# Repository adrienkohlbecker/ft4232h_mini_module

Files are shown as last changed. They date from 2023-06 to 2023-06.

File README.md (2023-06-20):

# FT4232H Mini Module Breakout

A breakout board for FTDI's FT4232H Mini Module. The size is friendly for breadboard use, with two rows of holes left available on each side of the breadboard for wires to come in.

## Board

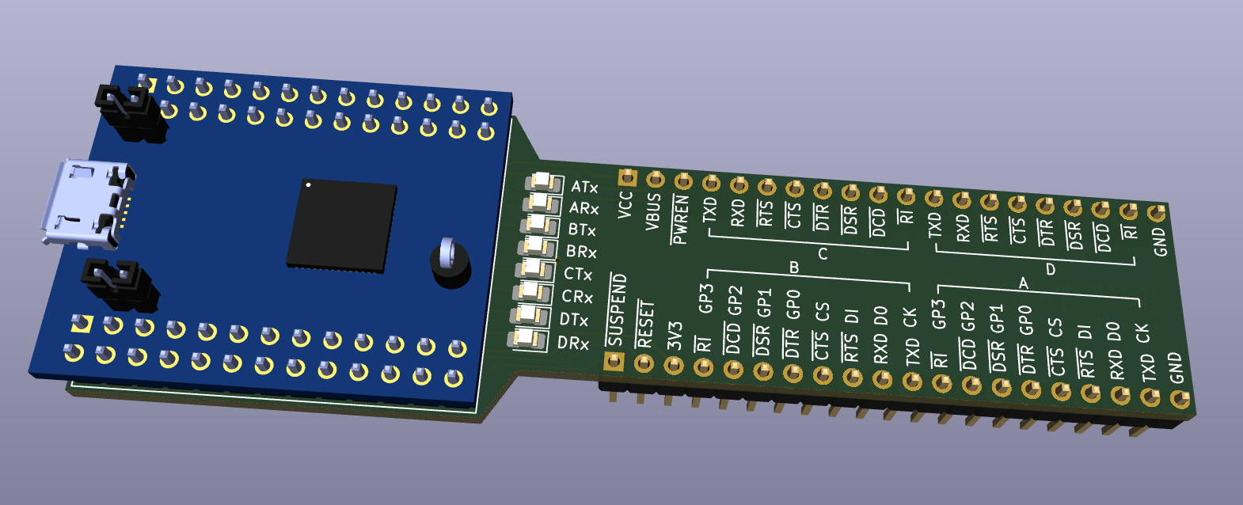
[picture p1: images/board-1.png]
board-1


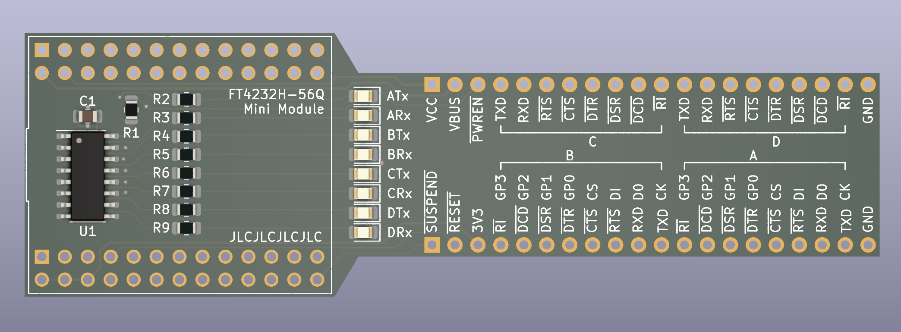
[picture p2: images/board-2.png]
board-2


## Schematic

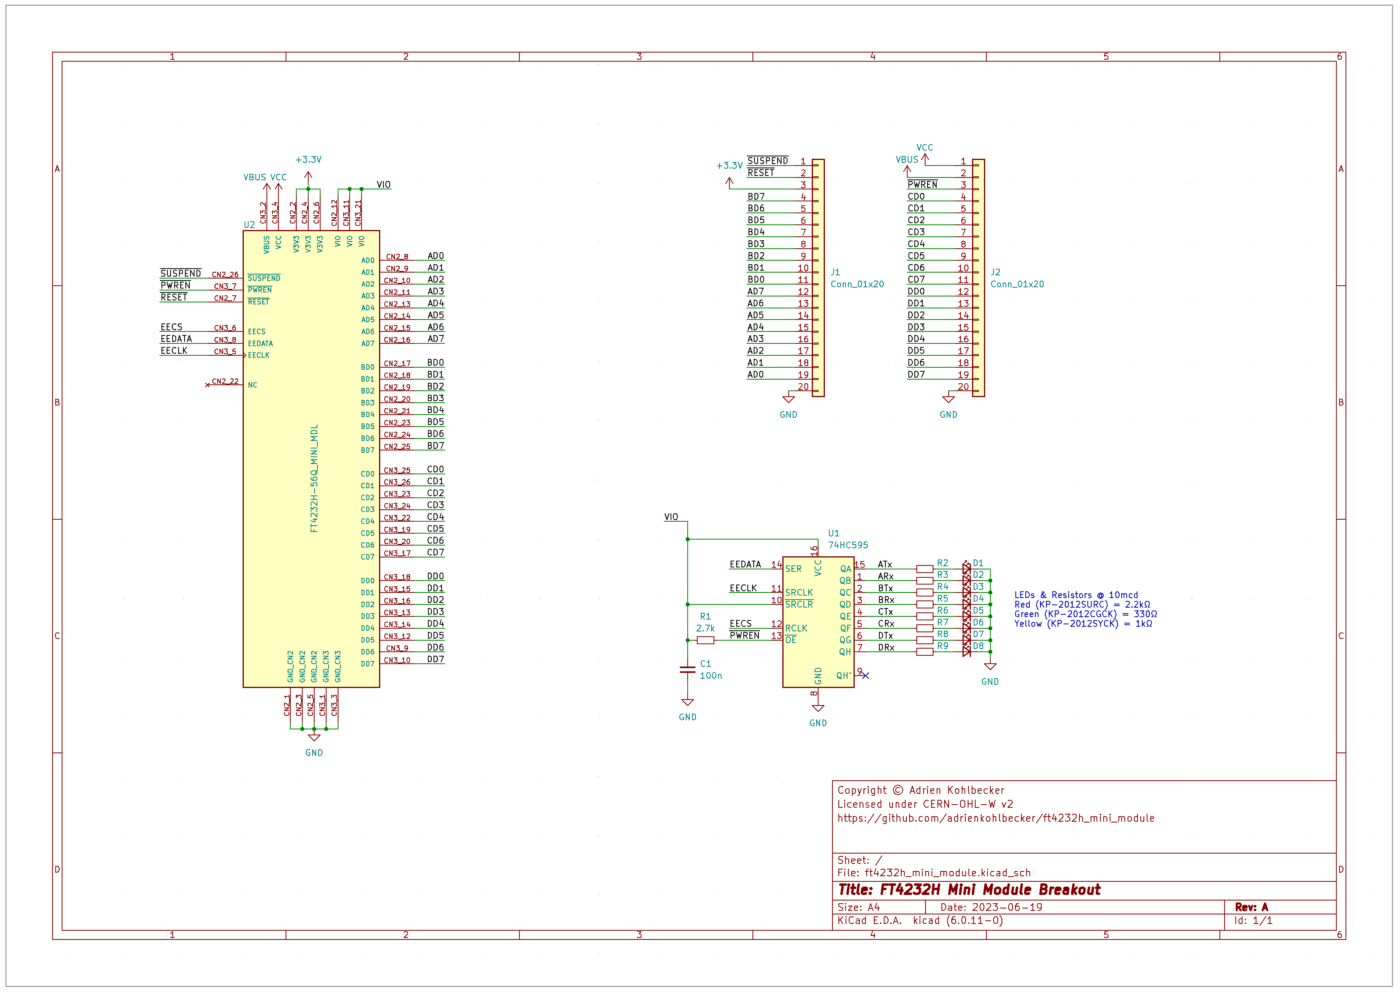
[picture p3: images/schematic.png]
schematic


## BOM

| Refs | Qty | Component | Description |
| ----- | --- | ---- | --- |
| C1 | 1 | 100n | Ceramic capacitor, SMD 0805 |
| D1, D2, D3, D4, D5, D6, D7, D8 | 8 | LED | Light emitting diode, SMD 0805 |
| J1, J2 | 2 | Conn_01x20 | Generic connector, single row, 01x20 |
| R1 | 1 | 2.7k | Resistor, SMD 0805 |
| R2, R3, R4, R5, R6, R7, R8, R9 | 8 | R | Resistor, SMD 0805. Value depends on chosen LED |
| U1 | 1 | 74HC595 | 8-bit serial in/out Shift Register 3-State Outputs SOIC-16 |
| U2 | 1 | FT4232H-56Q_MINI_MDL | FT4232H Mini Module, or two 2x13 Dupont sockets |

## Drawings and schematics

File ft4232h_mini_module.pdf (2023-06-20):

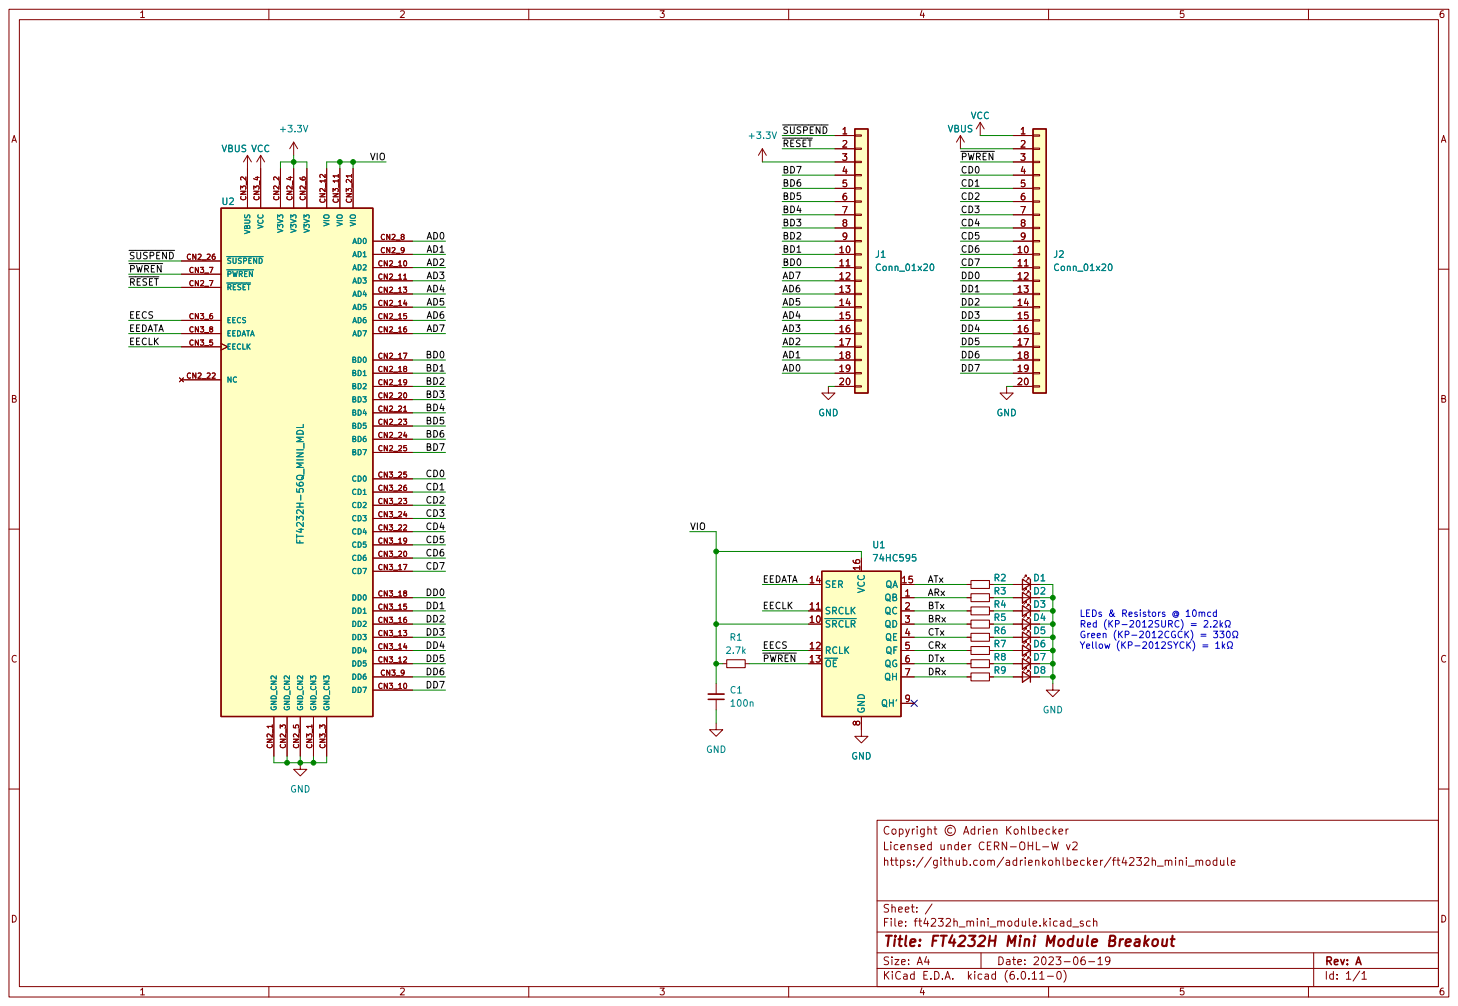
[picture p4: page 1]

Id: 1/1 Title: FT4232H Mini Module Breakout File: ft4232h_mini_module.kicad_sch Sheet: / https://github.com/adrienkohlbecker/ft4232h_mini_module

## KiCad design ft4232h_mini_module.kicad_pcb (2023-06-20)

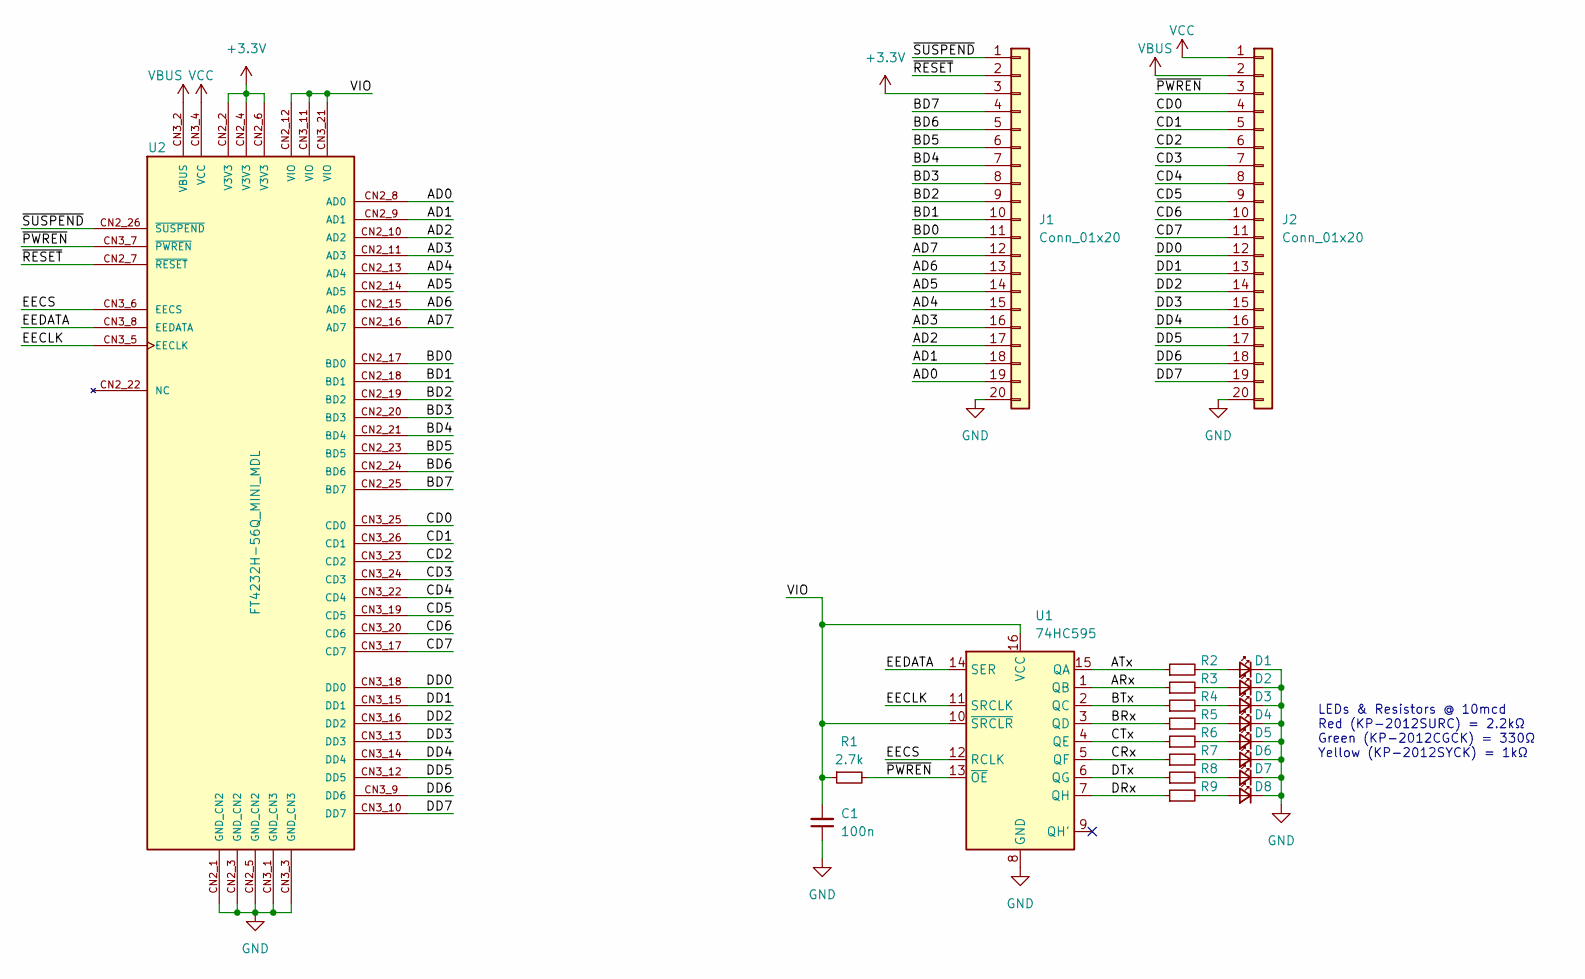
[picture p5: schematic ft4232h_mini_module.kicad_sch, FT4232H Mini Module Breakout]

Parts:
C1: 100n; C_0805_2012Metric_Pad1.18x1.45mm_HandSolder
D1, D2, D3, D4, D5, D6, D7, D8: LED; LED_0805_2012Metric_Pad1.15x1.40mm_HandSolder
J1, J2: Conn_01x20; PinHeader_1x20_P2.54mm_Vertical
R1: 2.7k; R_0805_2012Metric_Pad1.20x1.40mm_HandSolder
R2, R3, R4, R5, R6, R7, R8, R9: R; R_0805_2012Metric_Pad1.20x1.40mm_HandSolder
U1: 74HC595; SOIC-16_3.9x9.9mm_P1.27mm
U2: FT4232H-56Q_MINI_MDL; MODULE_FT4232H-56Q_MINI_MDL

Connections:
+3.3V: J1.3, U2.CN2_2 (V3V3), U2.CN2_4 (V3V3), U2.CN2_6 (V3V3)
/AD0: J1.19, U2.CN2_8 (AD0)
/AD1: J1.18, U2.CN2_9 (AD1)
/AD2: J1.17, U2.CN2_10 (AD2)
/AD3: J1.16, U2.CN2_11 (AD3)
/AD4: J1.15, U2.CN2_13 (AD4)
/AD5: J1.14, U2.CN2_14 (AD5)
/AD6: J1.13, U2.CN2_15 (AD6)
/AD7: J1.12, U2.CN2_16 (AD7)
/ARx: R3.1, U1.1 (QB)
/ATx: R2.1, U1.15 (QA)
/BD0: J1.11, U2.CN2_17 (BD0)
/BD1: J1.10, U2.CN2_18 (BD1)
/BD2: J1.9, U2.CN2_19 (BD2)
/BD3: J1.8, U2.CN2_20 (BD3)
/BD4: J1.7, U2.CN2_21 (BD4)
/BD5: J1.6, U2.CN2_23 (BD5)
/BD6: J1.5, U2.CN2_24 (BD6)
/BD7: J1.4, U2.CN2_25 (BD7)
/BRx: R5.1, U1.3 (QD)
/BTx: R4.1, U1.2 (QC)
/CD0: J2.4, U2.CN3_25 (CD0)
/CD1: J2.5, U2.CN3_26 (CD1)
/CD2: J2.6, U2.CN3_23 (CD2)
/CD3: J2.7, U2.CN3_24 (CD3)
/CD4: J2.8, U2.CN3_22 (CD4)
/CD5: J2.9, U2.CN3_19 (CD5)
/CD6: J2.10, U2.CN3_20 (CD6)
/CD7: J2.11, U2.CN3_17 (CD7)
/CRx: R7.1, U1.5 (QF)
/CTx: R6.1, U1.4 (QE)
/DD0: J2.12, U2.CN3_18 (DD0)
/DD1: J2.13, U2.CN3_15 (DD1)
/DD2: J2.14, U2.CN3_16 (DD2)
/DD3: J2.15, U2.CN3_13 (DD3)
/DD4: J2.16, U2.CN3_14 (DD4)
/DD5: J2.17, U2.CN3_12 (DD5)
/DD6: J2.18, U2.CN3_9 (DD6)
/DD7: J2.19, U2.CN3_10 (DD7)
/DRx: R9.1, U1.7 (QH)
/DTx: R8.1, U1.6 (QG)
/EECLK: U1.11 (SRCLK), U2.CN3_5 (EECLK)
/EECS: U1.12 (RCLK), U2.CN3_6 (EECS)
/EEDATA: U1.14 (SER), U2.CN3_8 (EEDATA)
/VIO: C1.2, R1.1, U1.10 (~SRCLR), U1.16 (VCC), U2.CN2_12 (VIO), U2.CN3_11 (VIO), U2.CN3_21 (VIO)
/~PWREN: J2.3, R1.2, U1.13 (~OE), U2.CN3_7 (~PWREN)
/~RESET: J1.2, U2.CN2_7 (~RESET)
/~SUSPEND: J1.1, U2.CN2_26 (~SUSPEND)
GND: C1.1, D1.1 (K), D2.1 (K), D3.1 (K), D4.1 (K), D5.1 (K), D6.1 (K), D7.1 (K), D8.1 (K), J1.20, J2.20, U1.8 (GND), U2.CN2_1 (GND_CN2), U2.CN2_3 (GND_CN2), U2.CN2_5 (GND_CN2), U2.CN3_1 (GND_CN3), U2.CN3_3 (GND_CN3)
unnamed: D1.2 (A), R2.2
unnamed: D2.2 (A), R3.2
unnamed: D3.2 (A), R4.2
unnamed: D4.2 (A), R5.2
unnamed: D5.2 (A), R6.2
unnamed: D6.2 (A), R7.2
unnamed: D7.2 (A), R8.2
unnamed: D8.2 (A), R9.2
VBUS: J2.2, U2.CN3_2 (VBUS)
VCC: J2.1, U2.CN3_4 (VCC)

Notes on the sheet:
LEDs & Resistors @ 10mcd Red (KP-2012SURC) = 2.2kΩ Green (KP-2012CGCK) = 330Ω Yellow (KP-2012SYCK) = 1kΩ

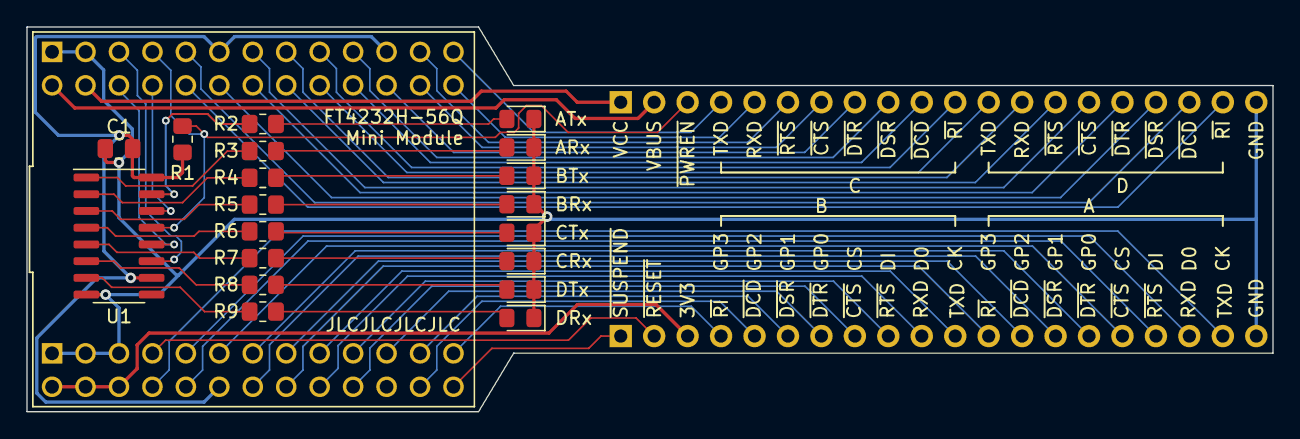
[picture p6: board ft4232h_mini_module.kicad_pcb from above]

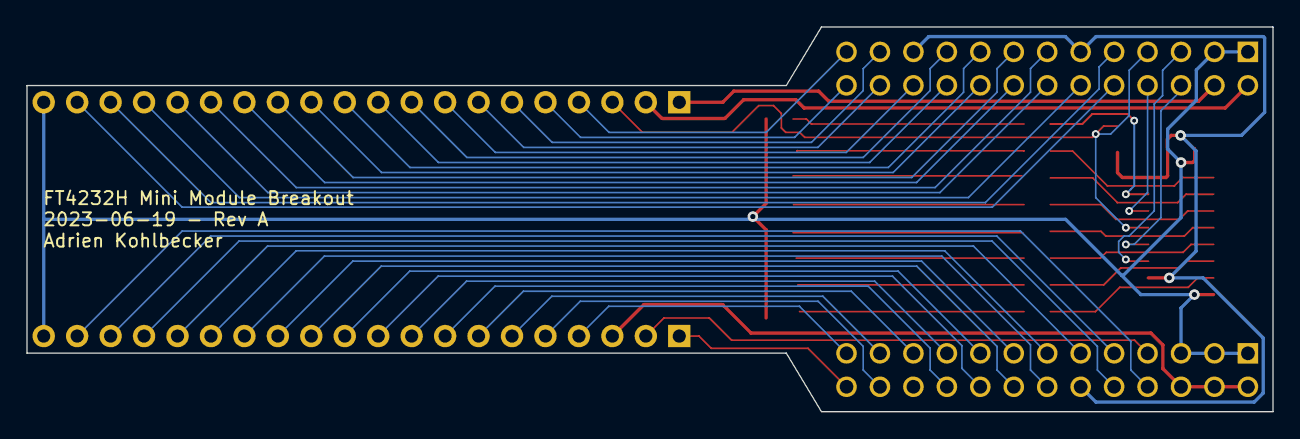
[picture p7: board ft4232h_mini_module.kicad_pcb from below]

Board: 2 copper layers, 94.6 x 29.2 mm, 22 parts (2 on the bottom side), 59 nets.

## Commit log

2023-06-19 Update template
    [kicad_template.kicad_pcb, kicad_template.kicad_sch]
2023-06-19 First release
    [ft4232h_mini_module-B_Cu.gbl, ft4232h_mini_module-B_Mask.gbs, ft4232h_mini_module-B_Paste.gbp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]

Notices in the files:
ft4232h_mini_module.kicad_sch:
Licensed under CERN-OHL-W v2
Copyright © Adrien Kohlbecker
